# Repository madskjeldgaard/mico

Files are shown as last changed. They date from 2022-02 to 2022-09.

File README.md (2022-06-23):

# Mico - A tiny, cheap Raspberry Pi Pico midi controller

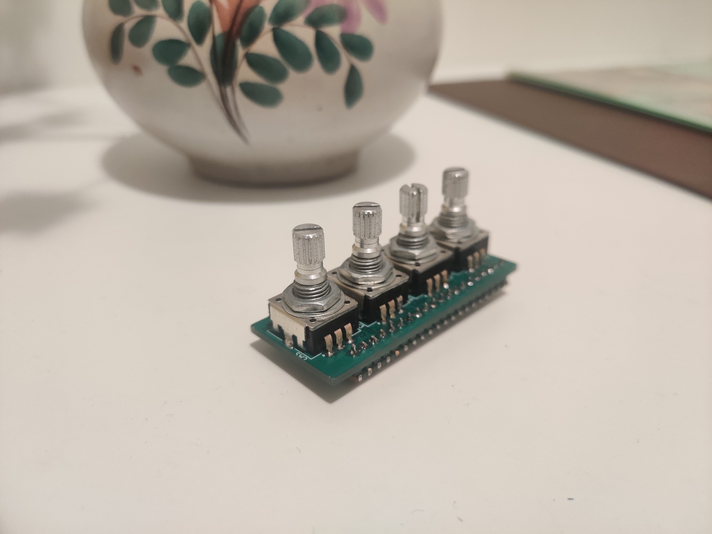
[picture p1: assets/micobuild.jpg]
mic build

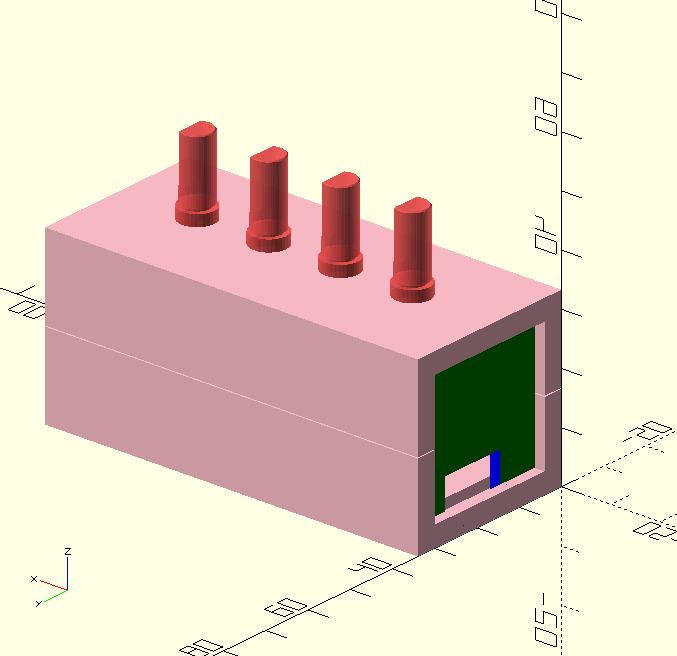
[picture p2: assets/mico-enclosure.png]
Enclosure
 

Mico is a small, cheap (~10 euros total) and super precise 14 bit midi controller based on the [Raspberry Pi Pico board](https://www.raspberrypi.com/products/raspberry-pi-pico/).

## Features
- 4 x detentless (smooth) encoders 
- Velocity: Slow movements result in microscopic changes (1/16000 of the max range approximately), fast movements in large changes.
- A variety of "clip modes" (cycle through them by pressing the button):
 	- wrap (when the value goes above max, it wraps back to 0) 
 	- clamp (clip at min and max value)
- 14 bit midi (as well as regular 7 bit midi)
- Cheap as chips and open sourced

## DEMO

There's a [demo here](https://vimeo.com/723291413).

## BOM

| Quantity | Part | Mouser Number |
|---|---|---|
| 1 | Raspberry Pi Pico rpi2040 | [474-DEV-17829](https://no.mouser.com/ProductDetail/SparkFun/DEV-17829?qs=sGAEpiMZZMv0NwlthflBi8NxDpSYKEiM3fbb2%2FVBX4k%3D) |
| 8 | 0.01uF capacitor, 0603 | [80-C0603C103M5R7411](https://no.mouser.com/ProductDetail/KEMET/C0603C103M5RAC7411?qs=ACslrEyEXNOtANB4TBkCnQ%3D%3D) |
| 16 | 10k resistors, 1%, 0603 | [603-RC0603FR-0710KL](https://no.mouser.com/ProductDetail/YAGEO/RC0603FR-0710KL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) |
| 4 | 15mm Detentless encoders | [652-PEC11R-4015K-N24](https://no.mouser.com/ProductDetail/652-PEC11R-4015K-N24)(knurled) / [PEC11R-4015F-N0024](https://no.mouser.com/ProductDetail/Bourns/PEC11R-4015F-N0024)(flat) |
| 2 | Female header (to sandwich between the boards)| n/a |
| 2 | Male header (to sandwich between the boards) | n/a |

## Uploading the firmware

Download the latest firmware from the release and locate the `mico.uf2` file. While plugging your Pico into your computer, press and hold the "BOOTSEL" button. It will show up as a storage device on your computer. Copy `mico.uf2` to this device. Done.

## Building and uploading the firmware (optional)

If you want to build the code and mess around with it, it is recommended to use a second Pico flashed with the [picoprobe](https://github.com/raspberrypi/picoprobe) firmware.

### Using picoprobe

```bash
cd software
mkdir build
cd build 
cmake ..
make && openocd -f interface/picoprobe.cfg -f target/rp2040.cfg -c "program mico.elf verify reset exit"
```
Debug:
```bash
openocd -f interface/picoprobe.cfg -f target/rp2040.cfg -s tcl
```

## Usage

### SuperCollider

There is an easy to use interface for this controller [here](https://github.com/madskjeldgaard/mico-sc).

## License

This work is shared under the *Attribution-NonCommercial-ShareAlike 4.0 International* license.

If you have questions about that, send me an email **mail at madskjeldgaard.dk**

## Credits

These projects were a big help and inspiration in making this:
- [schatzmann blog](https://www.pschatzmann.ch/home/2021/02/15/usb-midi-on-the-arduino-pico/) and [also this post](https://www.pschatzmann.ch/home/2021/02/19/tinyusb-a-simple-tutorial/)
- [pico-example-midi](https://github.com/infovore/pico-example-midi)
- [encoder-pio](https://github.com/pimoroni/pimoroni-pico) is from the pimoroni-pico library. MIT Licensed.

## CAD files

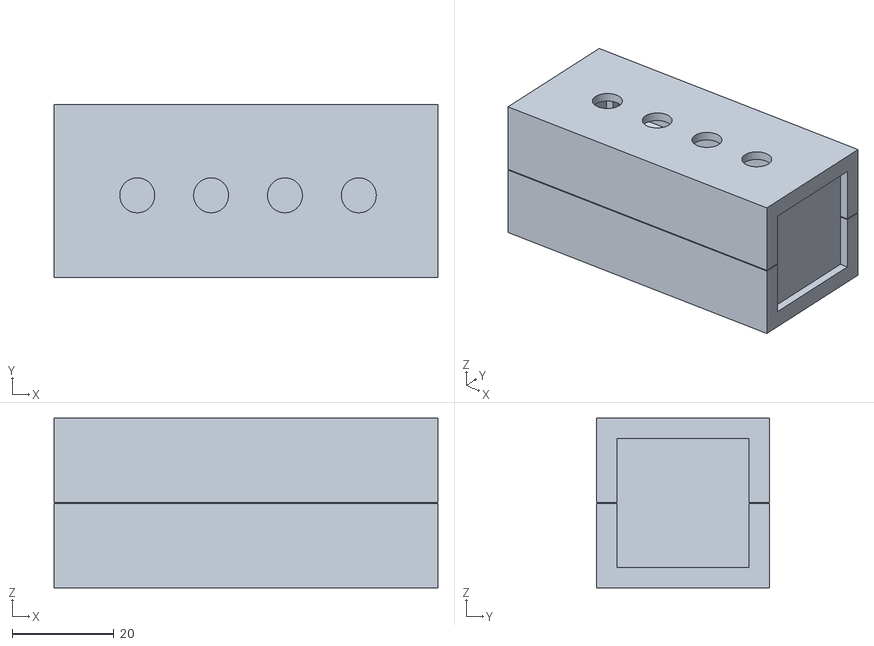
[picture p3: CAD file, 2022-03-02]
enclosure/mico_box.stl
75.4 x 34.0 x 33.3

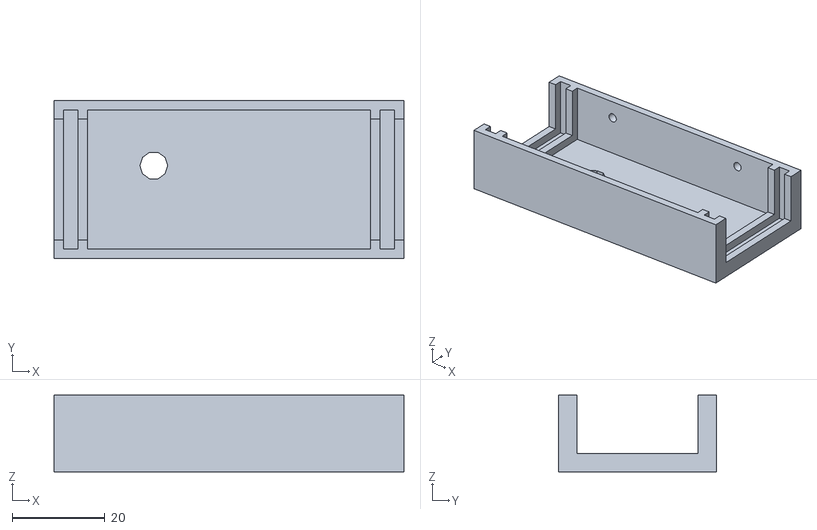
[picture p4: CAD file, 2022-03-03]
enclosure/print/bottom.stl
75.4 x 34.0 x 16.5

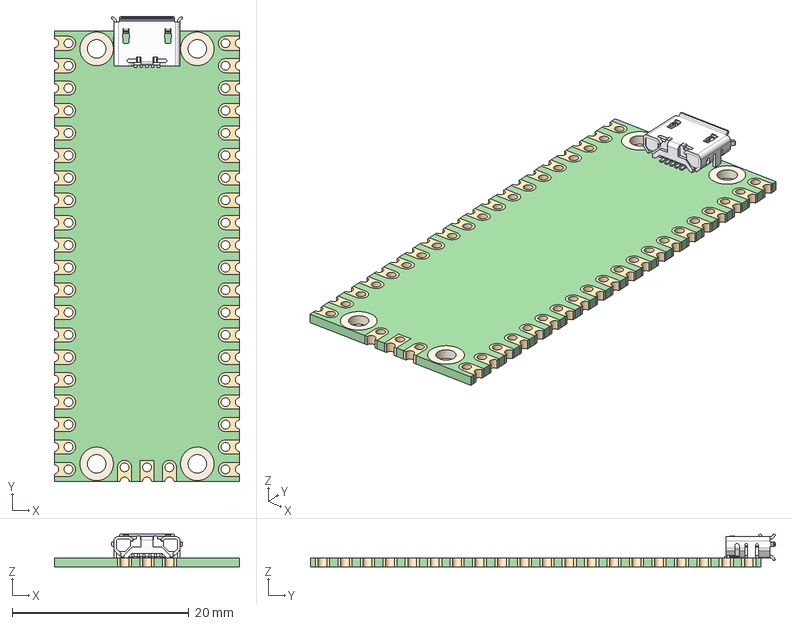
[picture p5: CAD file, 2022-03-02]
hardware/Raspberry Pi Pico.step
21.0 x 52.7 x 3.73 mm
PCB
Micro-USB_breakout v2

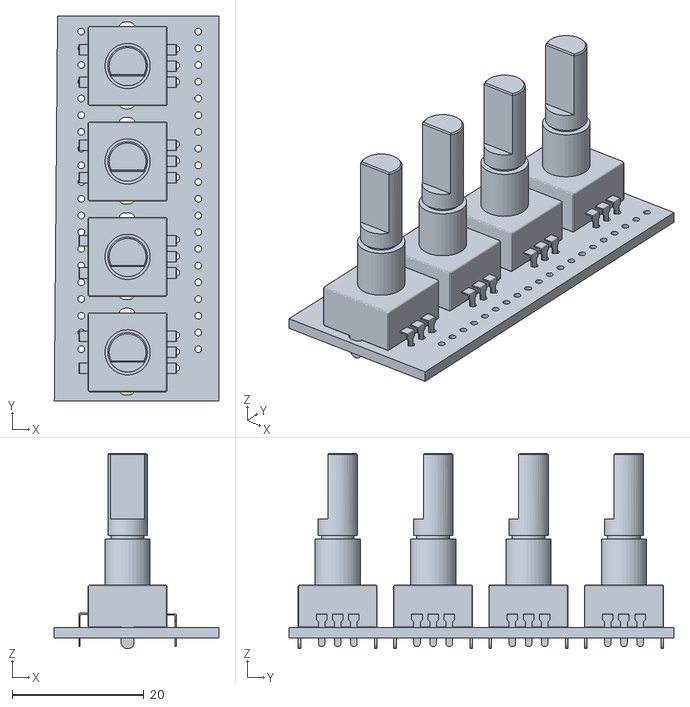
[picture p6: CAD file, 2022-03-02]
enclosure/mico-top-electronics.stl
25.0 x 58.5 x 29.7

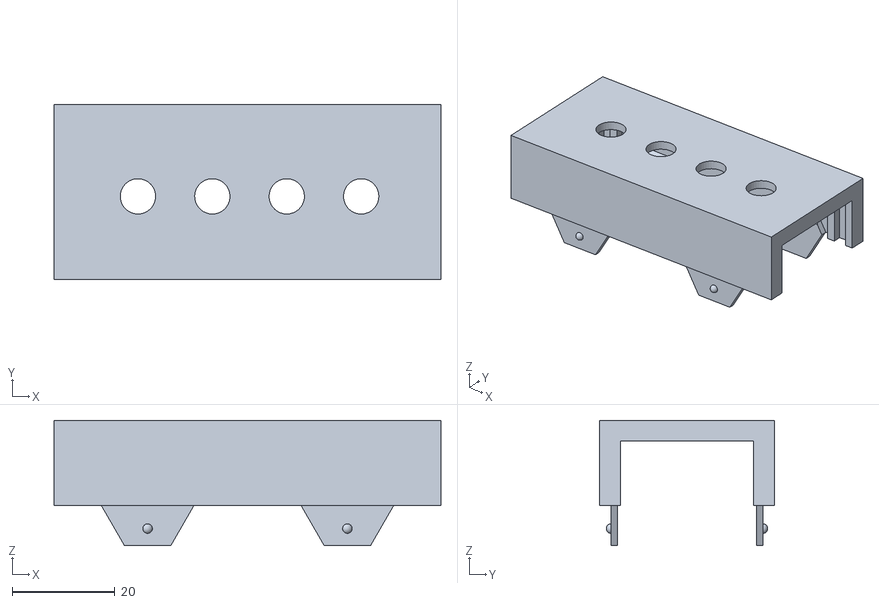
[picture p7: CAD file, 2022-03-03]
enclosure/print/top.stl
75.4 x 34.0 x 24.4

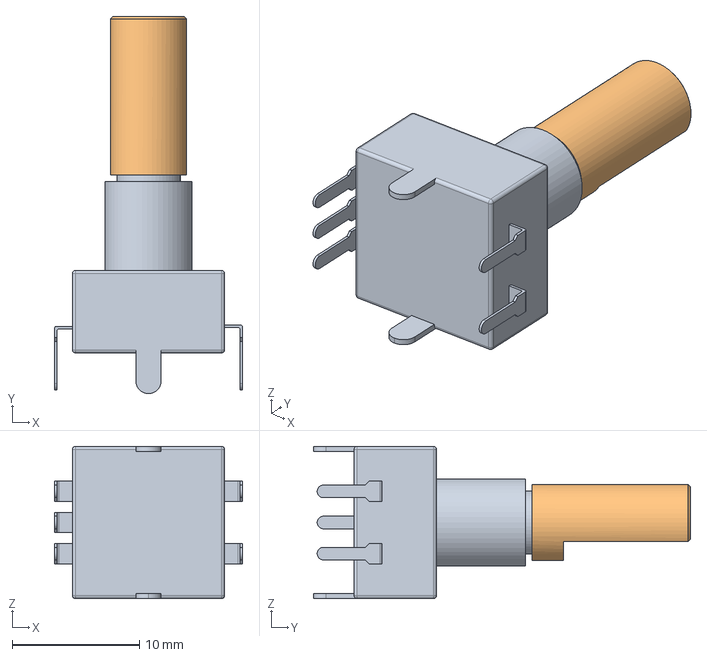
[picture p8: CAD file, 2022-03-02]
hardware/Rotary Encoder.step
14.8 x 29.7 x 12.0 mm

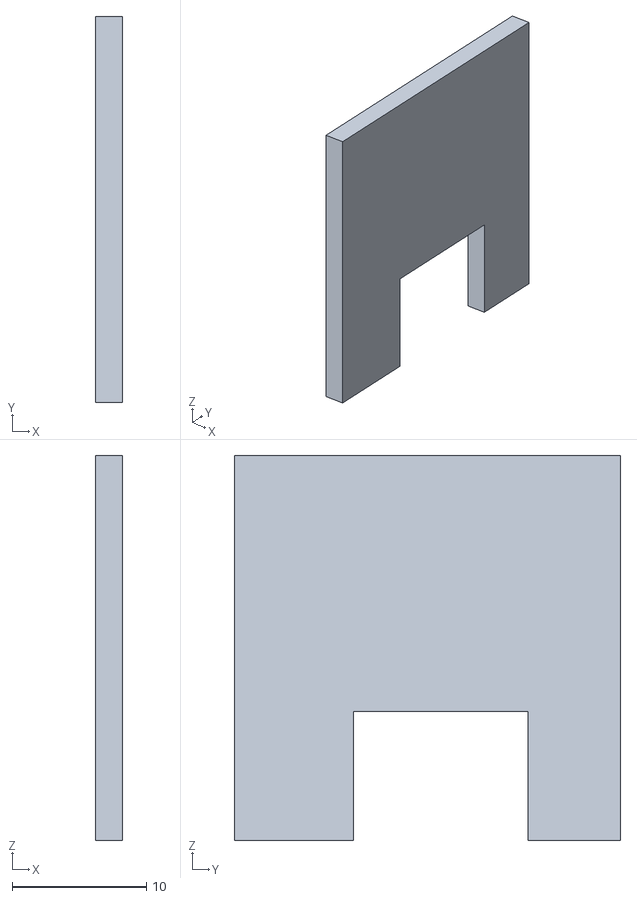
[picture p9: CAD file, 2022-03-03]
enclosure/print/back.stl
2.00 x 28.8 x 28.7

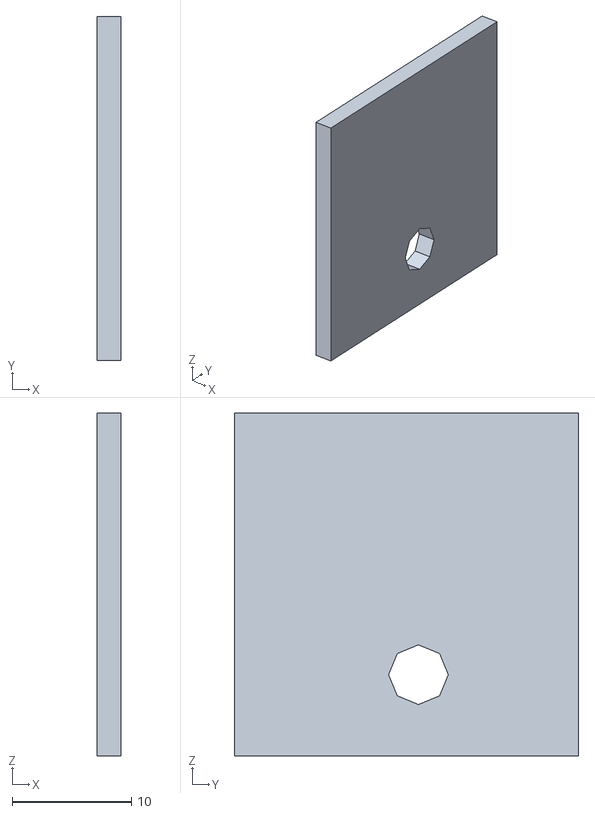
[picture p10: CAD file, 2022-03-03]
enclosure/print/front.stl
2.00 x 28.8 x 28.7

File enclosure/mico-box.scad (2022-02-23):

/* Box design originally by:
////////////////////////////////////////////////////////////////////
              -    FB Aka Heartman/Hearty 2016     -
              -   http://heartygfx.blogspot.com    -
              -       OpenScad Parametric Box      -
              -         CC BY-NC 3.0 License       -
////////////////////////////////////////////////////////////////////

Improved by jbebel:
http://github.com/jbebel/Ultimate-Box-Maker

To create a box, start by modifying the numerical parameters in the sections
below. This can be accomplished using a release of OpenSCAD newer than 2015.03.
As of the time of writing, this means that a development snapshot is required.
The Thingiverse Customizer may also potentially work, but at the time of
writing, it was inoperable.

The simplest choice is to hand-edit the .scad file. Feature toggles are
annotated with a comment. The other numerical parameters are measurements in
mm. Everything is parametrized, so if you double all the non-feature parameters
you will double the box size in every dimension. Certain parameters are derived
from other parameters. If you wish to override them, you may, but sensible
defaults have been chosen. Notably the design in this revision is particularly
PCB-centric, in that you should start with your PCB size and adjust the margins
around it to determine the box size. If you care more about the box size, you
can set the Length, Width, and Height explicitly, but read the comments around
them.

Once your box is sized appropriately, you can use the Panel modules to design
the holes and text for the front and back panels. Helper variables are provided
to assist you in positioning these holes relative to the PCB, if your holes are
for PCB-mounted components.

When you are ready to print, adjust the values in the "STL element to export"
section, and export each part one at a time.

Experimental options are provided for a screwless design, but these are
untested. In particular, the box fixation tabs may need thicknesses adjusted
in order to have the appropriate flexibility.
*/

// preview[view:north east, tilt:top diagonal]
//----------------------- Box parameters ---------------------------

/* [Box options] */
// - Wall thickness
Thick = 3;
// - Panel thickness
PanelThick = 3;
// - Font Thickness
FontThick = 0.5;
// - Filet Radius
Filet = 0;
// - 0 for beveled, 1 for rounded
Round = 0; // [0:No, 1:Yes]
// - Printer margin around interior cutouts
CutoutMargin = 0.3;
// - Margin between mating parts
PartMargin = 0.1;
// - PCB feet? (x4)
PCBFeet = 1; // [0:No, 1:Yes]
// - Decorations?
Decorations = 0; // [0:No, 1:Yes]
// - Decorations to ventilation holes
Vent = 0; // [0:No, 1:Yes]
// - Decoration-Holes width (in mm)
Vent_width = 1.5;
// - Tolerance (Panel/rails gap on one edge)
PanelThickGap = CutoutMargin + PartMargin;
PanelVerticalGap = PartMargin;
PanelHorizontalGap = CutoutMargin + PartMargin;

/* [Box Fixation Tabs] */
// - Side screw hole (or snap) diameter
ScrewHole = 2.2606;
// - Screw thread major diameter for outer shell
BoxHole = 2.8448;
// Thickness of fixation tabs
TabThick = 2;
// Back left tab
BLTab = 1; // [0:Bottom, 1:Top]
// Back right tab
BRTab = 1; // [0:Bottom, 1:Top]
// Front left tab
FLTab = 1; // [0:Bottom, 1:Top]
// Front right tab
FRTab = 1; // [0:Bottom, 1:Top]
// EXPERIMENTAL: Snap tabs
SnapTabs = 1; // [0:Screws, 1:Snaps]

/* [PCB options] */
// - PCB Length
PCBLength = 58.5;
// - PCB Width
PCBWidth = 25;
// - PCB Thickness
PCBThick = 1.6;
// You likely need to maintain |TabThick| margin on the left and right for tabs
// and whatnot.
// - Margin between front panel and PCB
FrontEdgeMargin = 1;
// - Margin between back panel and PCB
BackEdgeMargin = 1;
// - Margin between left wall and PCB
LeftEdgeMargin = 1;
// - Margin between right wall and PCB
RightEdgeMargin = 1;
// - Margin between top of PCB and box top.
TopMargin = 30; // @TODO

/* [PCB_Feet] */
// - Foot height above box interior
FootHeight = 8;
// - Foot diameter
FootDia = 8;
// - Hole diameter, or peg for screwless design
FootHole = 2.2606; // tap size for #4 coarse-thread
// - EXPERIMENTAL Screwless design
Screwless = 0; // [0:Screws, 1:Screwless]
FootFilet = FootHeight/4;

// Foot centers are specified as distance from PCB back-left corner.
// X is along the "length" axis, and Y is along the "width" axis.
// - Foot 1 distance from back PCB edge
Foot1X = 5;
// - Foot 1 distance from left PCB edge
Foot1Y = 5;
// - Foot 2 distance from back PCB edge
Foot2X = 5;
// - Foot 2 distance from right PCB edge
Foot2YFromEdge = 5;
Foot2Y = PCBWidth - Foot2YFromEdge;
// - Foot 3 distance from front PCB edge
Foot3XFromEdge = 5;
Foot3X = PCBLength - Foot3XFromEdge;
// - Foot 3 distance from left PCB edge
Foot3Y = 5;
// - Foot 4 distance from front PCB edge
Foot4XFromEdge = 5;
Foot4X = PCBLength - Foot4XFromEdge;
// - Foot 4 distance from right PCB edge
Foot4YFromEdge = 5;
Foot4Y = PCBWidth - Foot4YFromEdge;

/* [STL element to export] */
// - Top shell
TShell = 0; // [0:No, 1:Yes]
// - Bottom shell
BShell = 1; // [0:No, 1:Yes]
// - Front panel
FPanL = 1; // [0:No, 1:Yes]
// - Back panel
BPanL = 1; // [0:No, 1:Yes]
// - Panel holes and text
PanelFeatures = 1; // [0:No, 1:Yes]

/* [Hidden] */
// - Shell color
Couleur1 = "Orange";
// - Panel color
Couleur2 = "OrangeRed";
// - Text color
TextColor = "White";
// - making decorations thicker if it is a vent to make sure they go through
// shell
// Add a small number to Thick in case Filet is 0.
Dec_Thick = Vent ? Thick*1.001 + Filet : Thick/2;
// Separate vents with a square pillar by default.
Dec_Spacing = Thick + Vent_width;
// X offset to center of first vent
Dec_Offset = Thick*2 + PanelThick + PanelThickGap*2 + Dec_Spacing - Vent_width/2;

// Resolution based on Round parameter. Set this first number to something
// smaller to speed up processing. It should always be a multiple of 4.
Resolution = Round ? 100: 4;

/* Calculate box dimensions from PCB. If you want a more box-centric design
   where the outer diameter of the box matters more than the margins around
   the PCB you can set these manually. The PCB will still be placedaccording
   to the left and back margins, and if you want to use the screwless box
   design, you will need to set the TopMargin to
   (Height - Thick*2 - FootHeight - PCBThick)
*/
Length = PCBLength + FrontEdgeMargin + BackEdgeMargin + ((Thick + PanelThick + PanelThickGap*2)*2);
Width = PCBWidth + LeftEdgeMargin + RightEdgeMargin + Thick*2;
Height = FootHeight + PCBThick + TopMargin + Thick*2;
echo("Box: ", Length=Length, Width=Width, Height=Height);
// X position inset of mounting holes and tabs
MountInset = Thick*3 + PanelThick + PanelThickGap*2 + ScrewHole*4;

// Calculate panel dimensions from box dimensions.
PanelWidth = Width - Thick*2 - PanelHorizontalGap*2;
PanelHeight = Height - Thick*2 - PanelVerticalGap*2;

/*  Panel Manager

    Use the below 4 modules to produce holes and text on the front and back
    panels. The holes modules should contain instances of SquareHole or
    CylinderHole defined later in this file. The text modules should contain
    instances of LText or CText defined later in this file. It is
    recommended to use variables that you define for your needs to create
    the size and positions of these objects.
*/

// Calculate board-relative positions with respect to the panel, for
// convenience in placing panel elements.
TopOfBoardWRTPanel = FootHeight + PCBThick - PanelVerticalGap;
LeftEdgeOfBoardWRTFPanel = LeftEdgeMargin - PanelHorizontalGap;
LeftEdgeOfBoardWRTBPanel = RightEdgeMargin - PanelHorizontalGap;
// Visible panel edges
PanelBottomEdge = Thick - PanelVerticalGap;
PanelTopEdge = PanelHeight - Thick + PanelVerticalGap;
PanelLeftEdge = Thick - PanelHorizontalGap;
PanelRightEdge = PanelWidth - Thick + PanelHorizontalGap;

// Holes for front panel
module FPanelHoles() {
    // SquareHole(On/Off, Xpos,Ypos,Length,Width,Filet)
    /* SquareHole(1, 20, 20, 15, 10, 1); */
    /* SquareHole(1, 40, 20, 15, 10, 1); */
    /* SquareHole(1, 60, 20, 15, 10, 1); */
    // CylinderHole(On/Off, Xpos, Ypos, Diameter)
    /* CylinderHole(1, 27, 40, 8); */
    /* CylinderHole(1, 47, 40, 8); */
    /* CylinderHole(1, 67, 40, 8); */
    /* SquareHole(1, 20, 50, 80, 30, 3); */
    /* CylinderHole(1, 93, 30, 10); */
    /* SquareHole(1, 120, 20, 30, 60, 3); */
}

// Text for front panel
module FPanelText() {
    // LText(On/Off, Xpos, Ypos, "Font", Size, "Text", "HAlign", "VAlign")
    /* LText(1, 20, 83, "Arial Black", 4, "Digital Screen", HAlign="left"); */
    /* LText(1, 120, 83, "Arial Black", 4, "Level", HAlign="left"); */
    /* LText(1, 20, 11, "Arial Black", 6, "  1     2      3", HAlign="left"); */
    // CText(On/Off, Xpos, Ypos, "Font", Size, Diameter, Arc(Deg), Starting Angle(Deg),"Text")
    /* CText(1, 93, 29, "Arial Black", 4, 10, 180, 0, */
    /*       ["1", "." , "3", "." , "5", "." , "7", "." , "9", "." , "11"]); */
}
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

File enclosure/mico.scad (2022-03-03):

/* Box design originally by:
////////////////////////////////////////////////////////////////////
              -    FB Aka Heartman/Hearty 2016     -
              -   http://heartygfx.blogspot.com    -
              -       OpenScad Parametric Box      -
              -         CC BY-NC 3.0 License       -
////////////////////////////////////////////////////////////////////

Improved by jbebel:
http://github.com/jbebel/Ultimate-Box-Maker

To create a box, start by modifying the numerical parameters in the sections
below. This can be accomplished using a release of OpenSCAD newer than 2015.03.
As of the time of writing, this means that a development snapshot is required.
The Thingiverse Customizer may also potentially work, but at the time of
writing, it was inoperable.

The simplest choice is to hand-edit the .scad file. Feature toggles are
annotated with a comment. The other numerical parameters are measurements in
mm. Everything is parametrized, so if you double all the non-feature parameters
you will double the box size in every dimension. Certain parameters are derived
from other parameters. If you wish to override them, you may, but sensible
defaults have been chosen. Notably the design in this revision is particularly
PCB-centric, in that you should start with your PCB size and adjust the margins
around it to determine the box size. If you care more about the box size, you
can set the Length, Width, and Height explicitly, but read the comments around
them.

Once your box is sized appropriately, you can use the Panel modules to design
the holes and text for the front and back panels. Helper variables are provided
to assist you in positioning these holes relative to the PCB, if your holes are
for PCB-mounted components.

When you are ready to print, adjust the values in the "STL element to export"
section, and export each part one at a time.

Experimental options are provided for a screwless design, but these are
untested. In particular, the box fixation tabs may need thicknesses adjusted
in order to have the appropriate flexibility.
*/

// preview[view:north east, tilt:top diagonal]
//----------------------- Box parameters ---------------------------

USBCutX=5;
USBCutY=18;
USBCutZ=8;
USBW=13;
USBH=10;
USBD=10;

// TODO: This is kind of guesswork
BUTTONX=21.5;
BUTTONY=23;
BUTTONZ=-3;

BUTTONW=5;
BUTTONH=25;
BUTTOND=6;

/* [Box options] */
// - Wall thickness
Thick = 1.0;
// - Panel thickness
PanelThick = 1.0;
// - Font Thickness
FontThick = 0.5;
// - Filet Radius
Filet = 2;
// - 0 for beveled, 1 for rounded
Round = 0; // [0:No, 1:Yes]
// - Printer margin around interior cutouts
CutoutMargin = 0.2;
// - Margin between mating parts
PartMargin = 0.05;
// - PCB feet? (x4)
PCBFeet = 0; // [0:No, 1:Yes]
// - Decorations?
Decorations = 0; // [0:No, 1:Yes]
// - Decorations to ventilation holes
Vent = 0; // [0:No, 1:Yes]
// - Decoration-Holes width (in mm)
Vent_width = 0.5;
// - Tolerance (Panel/rails gap on one edge)
PanelThickGap = CutoutMargin + PartMargin;
PanelVerticalGap = PartMargin;
PanelHorizontalGap = CutoutMargin + PartMargin;

/* [Box Fixation Tabs] */
// - Side screw hole (or snap) diameter
ScrewHole = 2.2606;
// - Screw thread major diameter for outer shell
BoxHole = 2.8448;
// Thickness of fixation tabs
TabThick = 1.5;
// Back left tab
BLTab = 1; // [0:Bottom, 1:Top]
// Back right tab
BRTab = 1; // [0:Bottom, 1:Top]
// Front left tab
FLTab = 1; // [0:Bottom, 1:Top]
// Front right tab
FRTab = 1; // [0:Bottom, 1:Top]
// EXPERIMENTAL: Snap tabs
SnapTabs = 1; // [0:Screws, 1:Snaps]

/* [PCB options] */
// - PCB Length
PCBLength = 60.0;
// - PCB Width
PCBWidth = 26;
// - PCB Thickness
PCBThick = 1.6;
// You likely need to maintain |TabThick| margin on the left and right for tabs
// and whatnot.
// - Margin between front panel and PCB
FrontEdgeMargin = 3;
// - Margin between back panel and PCB
BackEdgeMargin = 2;
// - Margin between left wall and PCB
LeftEdgeMargin = 2;
// - Margin between right wall and PCB
RightEdgeMargin = 2;
// - Margin between top of PCB and box top.
TopMargin = 27.5; // @TODO

/* [PCB_Feet] */
// - Foot height above box interior
FootHeight = 0;
// - Foot diameter
FootDia = 8;
// - Hole diameter, or peg for screwless design
FootHole = 2.2606; // tap size for #4 coarse-thread
// - EXPERIMENTAL Screwless design
Screwless = 0; // [0:Screws, 1:Screwless]
FootFilet = FootHeight/4;

// Foot centers are specified as distance from PCB back-left corner.
// X is along the "length" axis, and Y is along the "width" axis.
// - Foot 1 distance from back PCB edge
Foot1X = 5;
// - Foot 1 distance from left PCB edge
Foot1Y = 5;
// - Foot 2 distance from back PCB edge
Foot2X = 5;
// - Foot 2 distance from right PCB edge
Foot2YFromEdge = 5;
Foot2Y = PCBWidth - Foot2YFromEdge;
// - Foot 3 distance from front PCB edge
Foot3XFromEdge = 5;
Foot3X = PCBLength - Foot3XFromEdge;
// - Foot 3 distance from left PCB edge
Foot3Y = 5;
// - Foot 4 distance from front PCB edge
Foot4XFromEdge = 5;
Foot4X = PCBLength - Foot4XFromEdge;
// - Foot 4 distance from right PCB edge
Foot4YFromEdge = 5;
Foot4Y = PCBWidth - Foot4YFromEdge;

TShell = 1;
BShell = 1;
FPanL = 1;
BPanL = 1;
/* [STL element to export] */
// - Top shell
Solo = 0; // 0 = not solo, 1 = top, 2 = bottom, 3 = front, 4 = back

PanelFeatures = 0; // [0:No, 1:Yes]

/* [Hidden] */
// - Shell color
Couleur1 = "Pink";
// - Panel color
Couleur2 = "Green";
// - Text color
TextColor = "White";
// - making decorations thicker if it is a vent to make sure they go through
// shell
// Add a small number to Thick in case Filet is 0.
Dec_Thick = Vent ? Thick*1.001 + Filet : Thick/2;
// Separate vents with a square pillar by default.
Dec_Spacing = Thick + Vent_width;
// X offset to center of first vent
Dec_Offset = Thick*2 + PanelThick + PanelThickGap*2 + Dec_Spacing - Vent_width/2;

// Resolution based on Round parameter. Set this first number to something
// smaller to speed up processing. It should always be a multiple of 4.
Resolution = Round ? 100: 4;

/* Calculate box dimensions from PCB. If you want a more box-centric design
   where the outer diameter of the box matters more than the margins around
   the PCB you can set these manually. The PCB will still be placedaccording
   to the left and back margins, and if you want to use the screwless box
   design, you will need to set the TopMargin to
   (Height - Thick*2 - FootHeight - PCBThick)
*/
Length = PCBLength + FrontEdgeMargin + BackEdgeMargin + ((Thick + PanelThick + PanelThickGap*2)*2);
Width = PCBWidth + LeftEdgeMargin + RightEdgeMargin + Thick*2;
Height = FootHeight + PCBThick + TopMargin + Thick*2;
echo("Box: ", Length=Length, Width=Width, Height=Height);
// X position inset of mounting holes and tabs
MountInset = Thick*3 + PanelThick + PanelThickGap*2 + ScrewHole*4;

// Calculate panel dimensions from box dimensions.
PanelWidth = Width - Thick*2 - PanelHorizontalGap*2;
PanelHeight = Height - Thick*2 - PanelVerticalGap*2;

/*  Panel Manager

    Use the below 4 modules to produce holes and text on the front and back
    panels. The holes modules should contain instances of SquareHole or
    CylinderHole defined later in this file. The text modules should contain
    instances of LText or CText defined later in this file. It is
    recommended to use variables that you define for your needs to create
    the size and positions of these objects.
*/

// Calculate board-relative positions with respect to the panel, for
// convenience in placing panel elements.
TopOfBoardWRTPanel = FootHeight + PCBThick - PanelVerticalGap;
LeftEdgeOfBoardWRTFPanel = LeftEdgeMargin - PanelHorizontalGap;
LeftEdgeOfBoardWRTBPanel = RightEdgeMargin - PanelHorizontalGap;
// Visible panel edges
PanelBottomEdge = Thick - PanelVerticalGap;
PanelTopEdge = PanelHeight - Thick + PanelVerticalGap;
PanelLeftEdge = Thick - PanelHorizontalGap;
PanelRightEdge = PanelWidth - Thick + PanelHorizontalGap;

// Holes for front panel
module FPanelHoles() {
    // SquareHole(On/Off, Xpos,Ypos,Length,Width,Filet)
    /* SquareHole(1, 20, 20, 15, 10, 1); */
    /* SquareHole(1, 40, 20, 15, 10, 1); */
    /* SquareHole(1, 60, 20, 15, 10, 1); */
    // CylinderHole(On/Off, Xpos, Ypos, Diameter)
    /* CylinderHole(1, 27, 40, 8); */
    /* CylinderHole(1, 47, 40, 8); */
    /* CylinderHole(1, 67, 40, 8); */
    /* SquareHole(1, 20, 50, 80, 30, 3); */
    /* CylinderHole(1, 93, 30, 10); */
    /* SquareHole(1, 120, 20, 30, 60, 3); */
}

// If using both the top and pico, the scad compiler will complain of meshes not being closed. Settings this to true will show the full electronics but it should be false when compiling the final model.
FullElectronics=false;
module Electronics(){
	// Electronics
	translate([-57.75,-120,22.8])rotate([0,0,90])
		if(FullElectronics){
			import("mico-all-electronics.stl", center=true);
		} else {
			import("mico-top-electronics.stl", center=true);
		}
}
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

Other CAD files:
hardware/KiCad-RP-Pico/SketchUp Model/Pico.skp

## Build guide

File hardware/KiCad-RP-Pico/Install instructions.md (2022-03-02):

# Install instructions

## 1. Copy the files locally

Copy the `RP-Pico Libraries` folder wherever you like on your computer.

## 2. Install the Raspberry Pi Pico board schema symbol

Use the `KiCad | Preferences | Manage Symbol Libraries...` command to manage the symbol library:

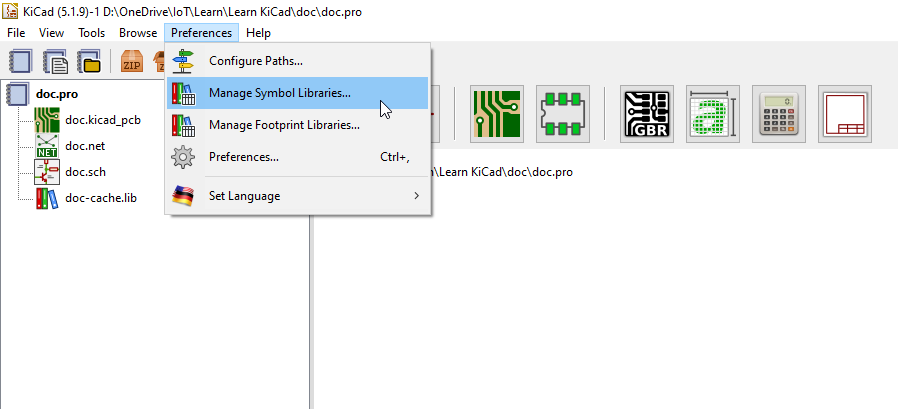
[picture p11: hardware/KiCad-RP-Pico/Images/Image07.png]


then select the global tab and click on the folder button:

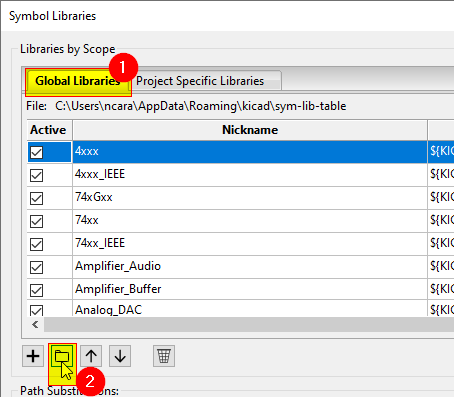
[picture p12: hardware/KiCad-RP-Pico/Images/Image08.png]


navigate to the `RP-Pico Libraries` folder, select the `MCU_RaspberryPi_and_Boards.lib` file and open it:

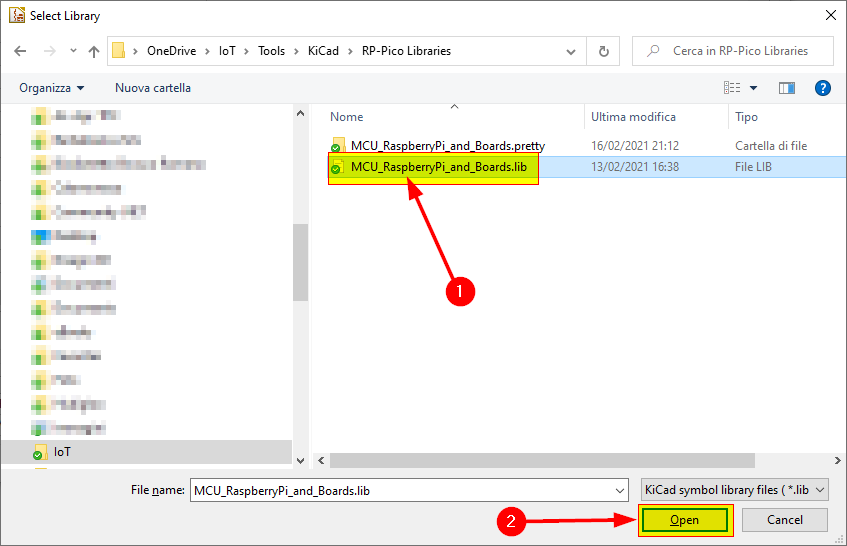
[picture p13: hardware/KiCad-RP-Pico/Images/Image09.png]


et voilà, the first step is completed:

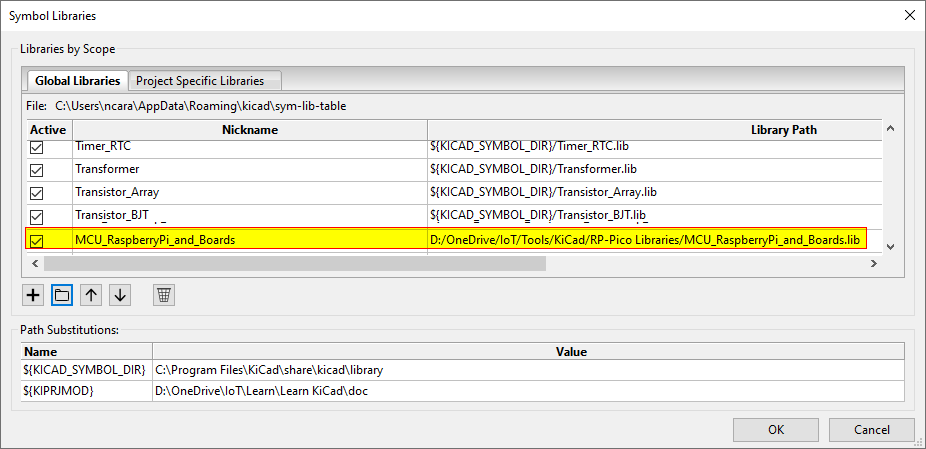
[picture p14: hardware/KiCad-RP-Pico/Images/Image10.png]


You can now close the symbol libraries manager window.

## 3. Install the Raspberry Pi Pico board footprint

You can use a similar approach to add the footprint to the footprint libraries manager, but I've found some issues that I've solved using the footprint editor, so here are the steps I suggest you to follow:

Open the footprint editor

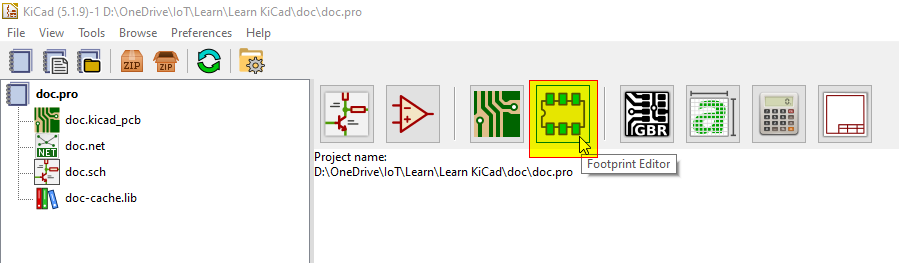
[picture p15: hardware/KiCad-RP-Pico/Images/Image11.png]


wait for the footprints to load... then use the `File | Add Library` command:

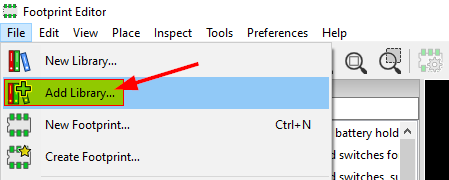
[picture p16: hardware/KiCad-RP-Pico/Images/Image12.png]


select the `MCU_RaspberriPi_and_Boards.pretty` folder (yes, the folder represent a footprint library on KiCad):

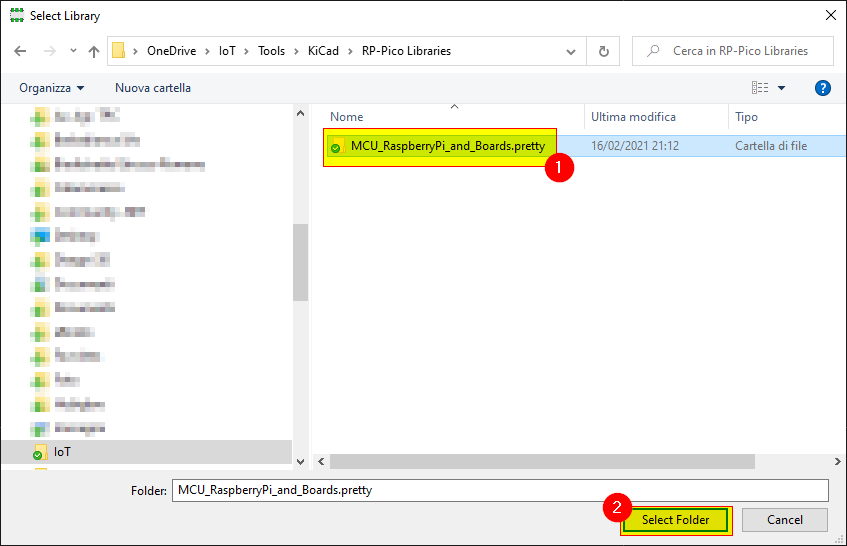
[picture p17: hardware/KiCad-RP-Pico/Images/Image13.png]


and confirm the `Global` choice:

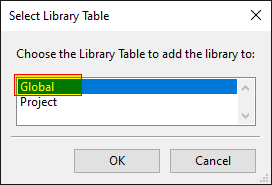
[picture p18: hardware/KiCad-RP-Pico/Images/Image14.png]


Now the library is installed on KiCad with the Raspberry Pi Pico footprint (double click on it to see it on the editor pane):

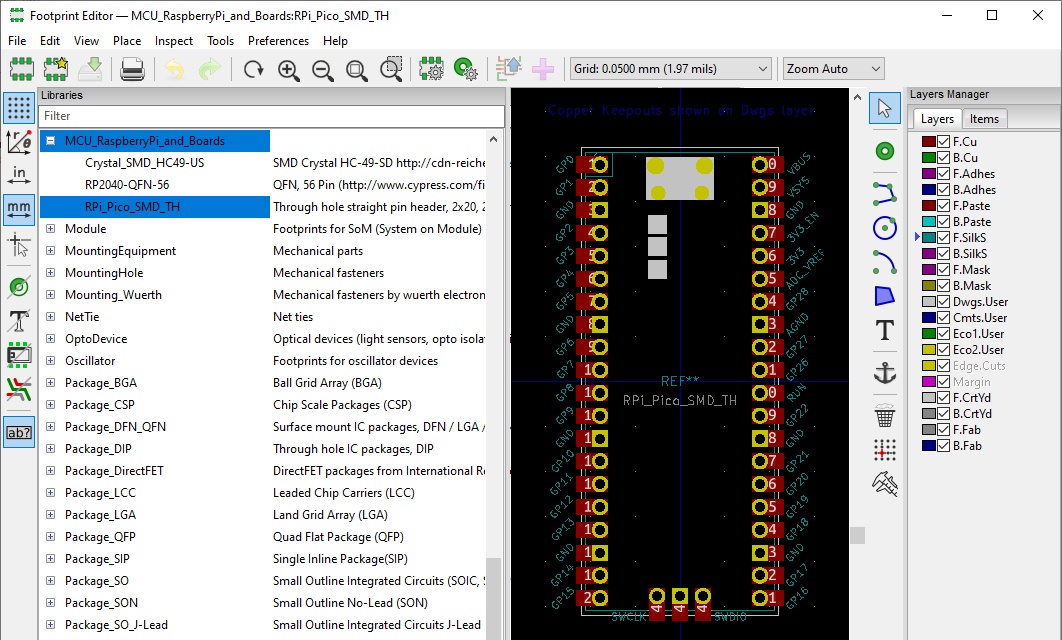
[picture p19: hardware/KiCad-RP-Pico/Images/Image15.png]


Don't close the windows as the next step start from here.

## 4. Install the Raspberry Pi Pico board footprint 3D visual

If not already open, open the the footprint editor

symbol library manager

double click on the `RPi_Pico_SMD_TH` footprint from the `MCU_RaspberriPi_and_Boards` library and then click on the `Footprint properties` icon:

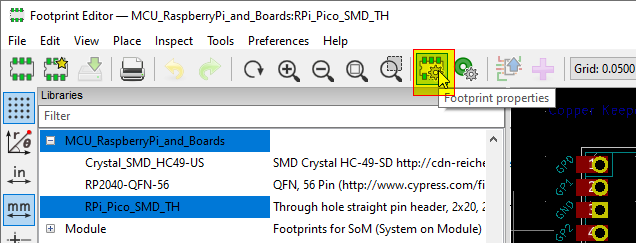
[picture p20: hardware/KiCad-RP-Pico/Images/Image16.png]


In the footprint properties window, first select the `3D Settings` tab. Please note that the preview shows only the PCB board with the footprint added on step 3, without any 3D representation of the Raspberry Pi Pico board. Now click on the folder icon to add the 3D model:

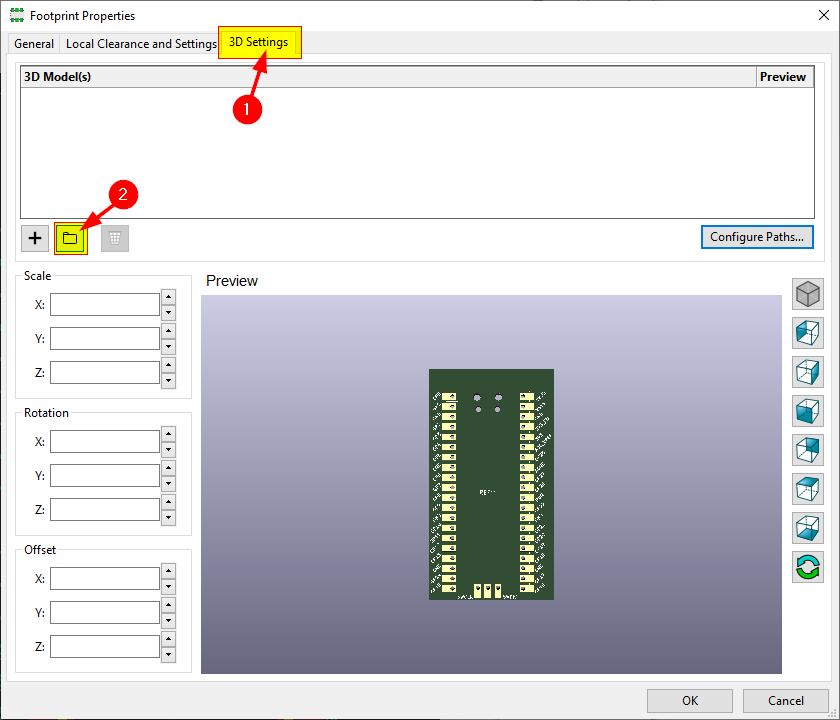
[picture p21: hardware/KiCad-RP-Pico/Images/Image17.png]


Navigate to the `RP-Pico Libraries` folder, select the `Pico.wrl` file and wait until the model is shown in the right panel, then confirm with OK:

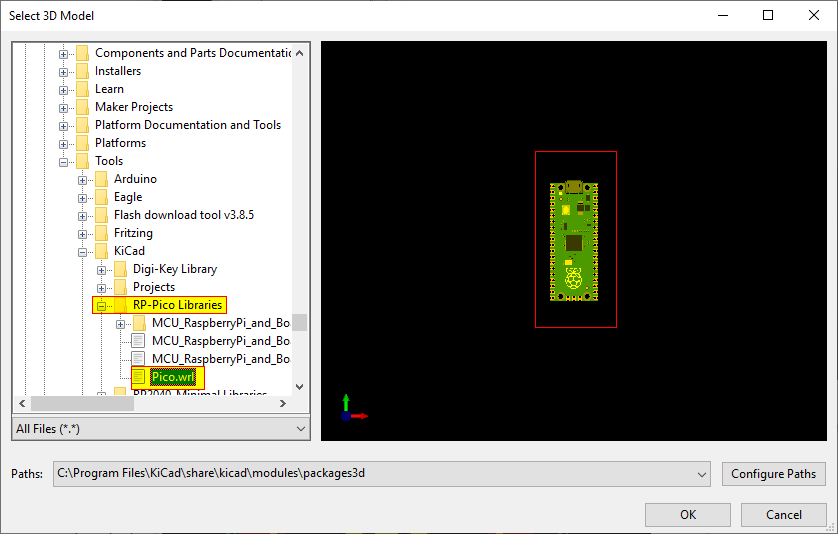
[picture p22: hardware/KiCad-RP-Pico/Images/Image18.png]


The model is already scaled and translated to match the footprint:

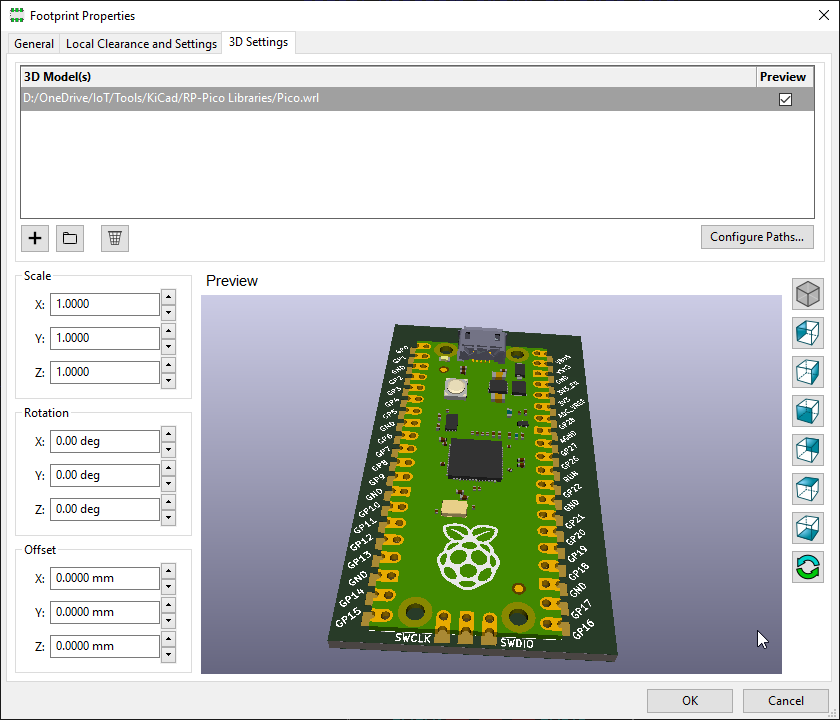
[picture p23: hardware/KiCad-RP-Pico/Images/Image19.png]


now close the `Footprint Properties` window, and the `Footprint Editor`, obviously saving the changes.

## Conclusion

Now that you've installed the schema and footprint and added the 3D model to the footprint, you can use the Raspberry Pi Pico board on your KiCad projects.

I've also added a test KiCad Project on the `Test` folder, that you can use to see an example of it.

Have fun!

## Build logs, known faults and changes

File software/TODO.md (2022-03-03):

Bugs:
- Button hole in enclosure
- debug hole in enclosure
- Properly clamp values under 0 in the encoder itself.

Features:
- VelocityTrigger
- Inverse on adjacent midi channel. So if enc1 is high on midi channel 0, then send inverse of that to 1 on channel 1
- Set wrap mode per encoder (hold button and wiggle encoder)
- Interpolation / lag
- Add interpolated random envelope mode
- save options in flash: https://github.com/raspberrypi/pico-examples/blob/master/flash/program/flash_program.c

Misc:
- Move encoder stuff to seperate library
- Remove all the microstep leftovers from gpio-encoder
- semaphores around usb midi stuff like in arduino_pico?

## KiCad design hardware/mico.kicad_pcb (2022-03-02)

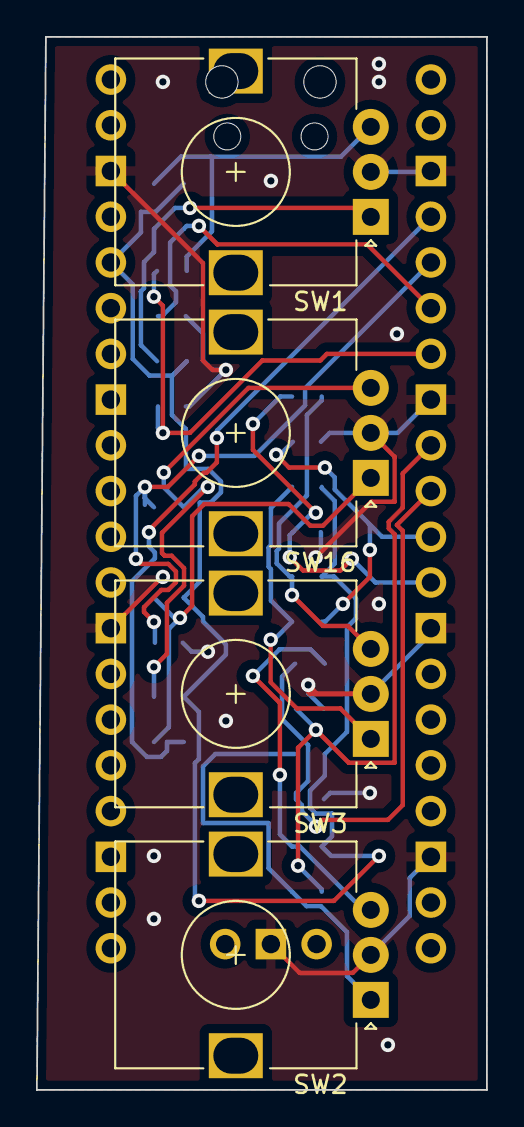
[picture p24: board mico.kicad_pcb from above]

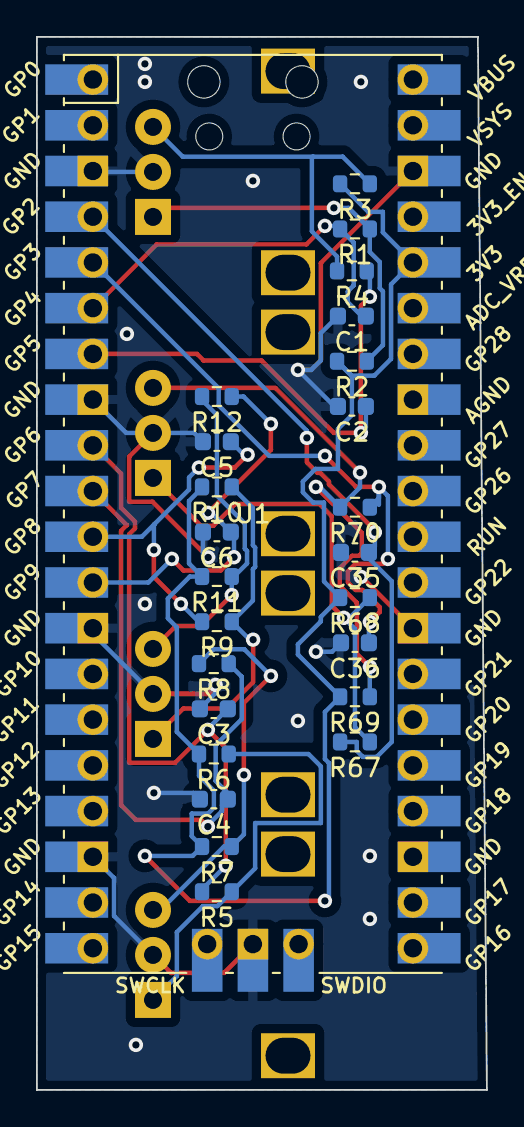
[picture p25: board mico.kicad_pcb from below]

Board: 2 copper layers, 25.0 x 58.5 mm, 29 parts (25 on the bottom side), 18 nets.

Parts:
C1, C2, C3, C4, C5, C6, C35, C36: 0.01uF; C_0603_1608Metric
R1, R2, R3, R4, R5, R6, R7, R8, R9, R10, R11, R12, R67, R68, R69, R70: 10k; R_0603_1608Metric
SW1, SW2, SW3, SW16: Rotary_Encoder; RotaryEncoder_Alps_EC12E_Vertical_H20mm
U1: Pico; RPi_Pico_SMD_TH

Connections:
+3V3: R2.2, R3.2, R6.2, R7.2, R10.2, R11.2, R68.2, R69.2, U1.36 (3V3)
/encoder_no_switch1/A: C1.1, R1.2, U1.6 (GPIO4)
/encoder_no_switch1/B: C2.1, R4.1, U1.7 (GPIO5)
/encoder_no_switch2/A: C3.1, R5.2, U1.9 (GPIO6)
/encoder_no_switch2/B: C4.1, R8.1, U1.10 (GPIO7)
/encoder_no_switch3/A: C5.1, R9.2, U1.11 (GPIO8)
/encoder_no_switch3/B: C6.1, R12.1, U1.12 (GPIO9)
/encoder_no_switch/A: C35.1, R67.2, U1.4 (GPIO2)
/encoder_no_switch/B: C36.1, R70.1, U1.5 (GPIO3)
GND: C1.2, C2.2, C3.2, C4.2, C5.2, C6.2, C35.2, C36.2, SW1.C, SW2.C, SW3.C, SW16.C, U1.3 (GND), U1.8 (GND), U1.13 (GND), U1.18 (GND), U1.28 (GND), U1.38 (GND), U1.42 (GND)
unnamed: R1.1, R2.1, SW1.A
unnamed: R3.1, R4.2, SW1.B
unnamed: R5.1, R6.1, SW2.A
unnamed: R7.1, R8.2, SW2.B
unnamed: R9.1, R10.1, SW3.A
unnamed: R11.1, R12.2, SW3.B
unnamed: R67.1, R68.1, SW16.A
unnamed: R69.1, R70.2, SW16.B

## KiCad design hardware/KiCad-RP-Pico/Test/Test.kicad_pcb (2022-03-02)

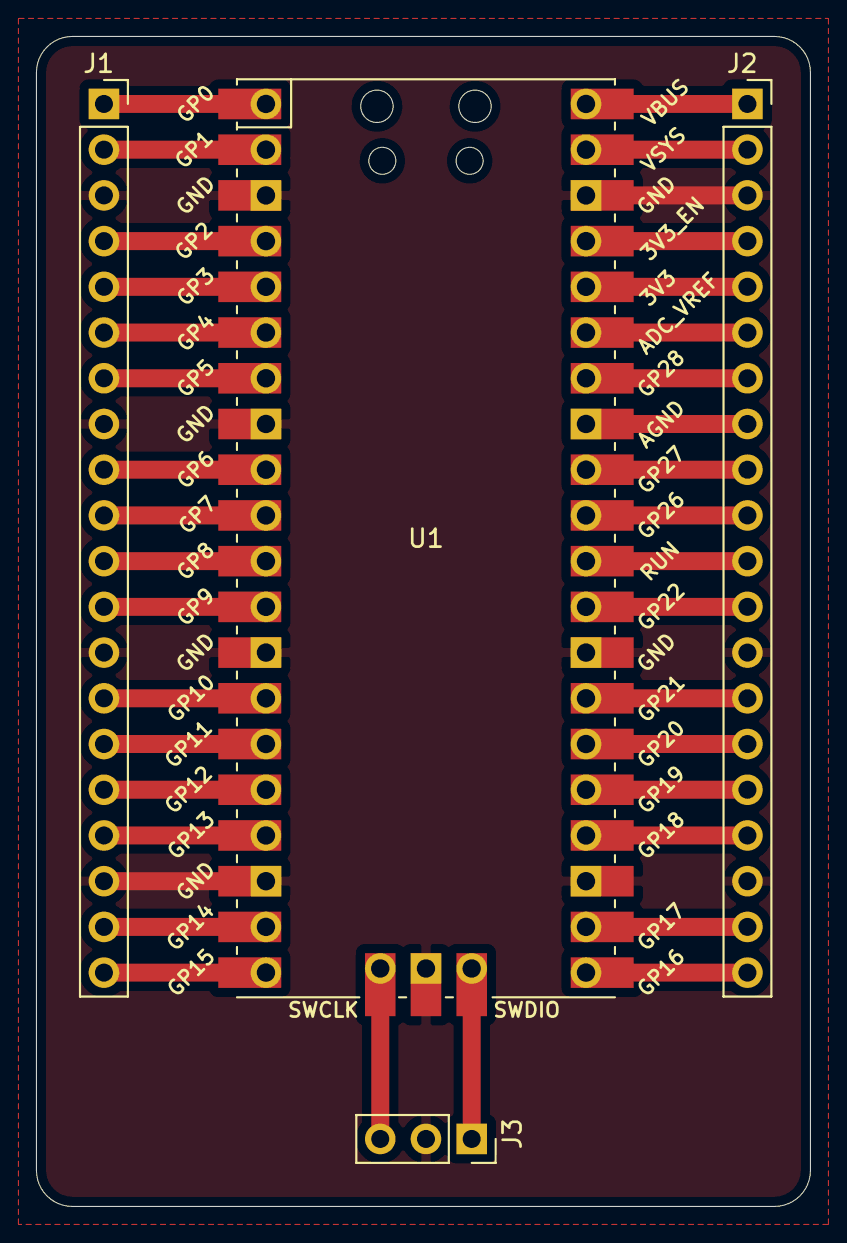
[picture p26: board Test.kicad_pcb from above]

Board: 2 copper layers, 43.0 x 65.0 mm, 4 parts (0 on the bottom side), 36 nets.

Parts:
J1, J2: Conn_01x20; PinSocket_1x20_P2.54mm_Vertical
J3: Conn_01x03; PinSocket_1x03_P2.54mm_Vertical
U1: Pico; RPi_Pico_SMD_TH

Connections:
GND: J1.3, J1.8, J1.13, J1.18, J2.3, J2.13, J2.18, J3.2, U1.3, U1.8, U1.13, U1.18, U1.23, U1.28, U1.38, U1.42
unnamed: J1.1, U1.1
unnamed: J1.2, U1.2
unnamed: J1.4, U1.4
unnamed: J1.5, U1.5
unnamed: J1.6, U1.6
unnamed: J1.7, U1.7
unnamed: J1.9, U1.9
unnamed: J1.10, U1.10
unnamed: J1.11, U1.11
unnamed: J1.12, U1.12
unnamed: J1.14, U1.14
unnamed: J1.15, U1.15
unnamed: J1.16, U1.16
unnamed: J1.17, U1.17
unnamed: J1.19, U1.19
unnamed: J1.20, U1.20
unnamed: J2.1, U1.40
unnamed: J2.2, U1.39
unnamed: J2.4, U1.37
unnamed: J2.5, U1.36
unnamed: J2.6, U1.35
unnamed: J2.7, U1.34
unnamed: J2.8, U1.33
unnamed: J2.9, U1.32
unnamed: J2.10, U1.31
unnamed: J2.11, U1.30
unnamed: J2.12, U1.29
unnamed: J2.14, U1.27
unnamed: J2.15, U1.26
unnamed: J2.16, U1.25
unnamed: J2.17, U1.24
unnamed: J2.19, U1.22
unnamed: J2.20, U1.21
unnamed: J3.1, U1.43
unnamed: J3.3, U1.41

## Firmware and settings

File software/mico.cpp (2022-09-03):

#include "bsp/board.h"
#include "hardware/gpio.h"
#include "hardware/interp.h"
#include "hardware/pio.h"
#include "hardware/structs/ioqspi.h"
#include "hardware/structs/sio.h"
#include "libs/encoder-pio/pioencoder.hpp"
#include "mico_midi.h"
#include "micoencoder.hpp"
#include "pico/binary_info.h"
#include "pico/stdlib.h"
#include "tusb.h"
#include "velocity.hpp"
#include "voice.hpp"
#include "timeralarm.hpp"
#include <stdio.h>

// Change this to true to enable parallel channel mode
#define PARALLEL_CHANNELS false

using namespace pimoroni;
using namespace mico;

auto clipmode = ClipMode::WRAP;
constexpr int channel = 1;
constexpr int numEncoders = 4;
#define LED_PIN PICO_DEFAULT_LED_PIN
bool buttonState;

// A voice is an encoder with midi sender, encoder class, velocity etc.
MicoVoice voices[numEncoders]{
  MicoVoice(4, 5, 14, channel, clipmode),
  MicoVoice(2, 3, 15, channel, clipmode),
  MicoVoice(8, 9, 16, channel, clipmode),
  MicoVoice(6, 7, 17, channel, clipmode),
};

void changeClipmodes(ClipMode newMode){
  for (size_t i = 0; i < numEncoders; i++) {
	voices[i].setClipMode(newMode);
  }
}

pico_arduino::TimerAlarmRepeating miditimer;

// UART defines
// By default the stdout UART is `uart0`, so we will use the second one
#define UART_ID uart0
#define BAUD_RATE 115200

// Device mounting callbacks
void tud_mount_cb(void) {
  printf("Mico mounted\n");
} // Invoked when device is mounted
void tud_umount_cb(void) {
  printf("Mico unmounted\n");
} // Invoked when device is unmounted
void tud_suspend_cb(bool remote_wakeup_en) {
  printf("Mico suspended\n");
} // Invoked when usb bus is suspended
void tud_resume_cb(void) {
  printf("Mico resumed\n");
} // Invoked when usb bus is resumed

// Picoboard has a button attached to the flash CS pin, which the bootrom
// checks, and jumps straight to the USB bootcode if the button is pressed
// (pulling flash CS low). We can check this pin in by jumping to some code in
// SRAM (so that the XIP interface is not required), floating the flash CS
// pin, and observing whether it is pulled low.
//
// This doesn't work if others are trying to access flash at the same time,
// e.g. XIP streamer, or the other core.
bool __no_inline_not_in_flash_func(get_bootsel_button)() {
  const uint CS_PIN_INDEX = 1;

  // Must disable interrupts, as interrupt handlers may be in flash, and we
  // are about to temporarily disable flash access!
  uint32_t flags = save_and_disable_interrupts();

  // Set chip select to Hi-Z
  hw_write_masked(&ioqspi_hw->io[CS_PIN_INDEX].ctrl,
                  GPIO_OVERRIDE_LOW << IO_QSPI_GPIO_QSPI_SS_CTRL_OEOVER_LSB,
                  IO_QSPI_GPIO_QSPI_SS_CTRL_OEOVER_BITS);

  // Note we can't call into any sleep functions in flash right now
  for (volatile int i = 0; i < 1000; ++i)
    ;

  // The HI GPIO registers in SIO can observe and control the 6 QSPI pins.
  // Note the button pulls the pin *low* when pressed.
  bool button_state = !(sio_hw->gpio_hi_in & (1u << CS_PIN_INDEX));

  // Need to restore the state of chip select, else we are going to have a
  // bad time when we return to code in flash!
  hw_write_masked(&ioqspi_hw->io[CS_PIN_INDEX].ctrl,
                  GPIO_OVERRIDE_NORMAL << IO_QSPI_GPIO_QSPI_SS_CTRL_OEOVER_LSB,
                  IO_QSPI_GPIO_QSPI_SS_CTRL_OEOVER_BITS);

  restore_interrupts(flags);

  return button_state;
}

void midi_task(void) {
  for (size_t voiceNum = 0; voiceNum < numEncoders; voiceNum++) {
    voices[voiceNum].update14();
  }
}

void button_task() {
  auto newState = get_bootsel_button();
  if (buttonState != newState) {
    buttonState = newState;

    // Toggle
    if (buttonState == 1) {
	  switch (clipmode) {
		case ClipMode::CLAMP:
		  clipmode = ClipMode::WRAP;
		  gpio_put(LED_PIN, 0);
		  break;
		case ClipMode::WRAP:
		  clipmode = ClipMode::CLAMP;
		  gpio_put(LED_PIN, 1);
		  break;
	  }

	  changeClipmodes(clipmode);
      printf("Changed clipmode to: %d\n", clipmode);
    }
  }
}

static bool loopTask(repeating_timer_t *rt){
  tud_task(); // tinyusb device task
  button_task();
  midi_task();
  return true;
}

inline void setup() {

  printf("Setting up Mico.\n");
  buttonState = get_bootsel_button();

  for (size_t voiceNum = 0; voiceNum < numEncoders; voiceNum++) {
    voices[voiceNum].init();
  }

  // Turn on LED
  gpio_init(LED_PIN);
  gpio_set_dir(LED_PIN, GPIO_OUT);
  gpio_put(LED_PIN, 0);

  printf("Starting midi timer\n");
  miditimer.start(loopTask, 1);
}
int main() {
  printf("Starting Mico main loop.\n");
  // TODO: Is this already done by Pico sdk?
  board_init();
  // Set up our UART
  uart_init(UART_ID, BAUD_RATE);
  stdio_init_all();
  tusb_init();
  setup();

  printf("Starting Mico loop.\n");

  while (true) {
    // sleep_ms(1);
  }

  return 0;
}

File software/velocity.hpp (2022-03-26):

/*
*
* TODO:
* - This whole business is probably overcomplicated somewhat. Clean it up and simplify it!
*
*/
#pragma once
#ifndef VEL
#define VEL

namespace mico{

enum Speed {
  SLOWEST=100000,
  SLOW=50000,
  MEDIUM=30000,
  FAST=20000,
  SUPERFAST=10000,
  FASTEST=5000,
};

// std::array<int, Speed::NUM_SPEEDS> deltaValues = {
//   1000,
//   500,
//   250,
//   50,
//   10,
//   5,
//   1,
// };

class Velocity {
public:
  // This is used outside of the class to figure out what level of velocity we are at.
  int speed_level{1};
  static const int num_speed_levels{7};

  void init(){
	t2 = time_us_32();
	update();
  }

  // Update clocks and return the delta value (velocity applied to 14 bit midi value range)
  uint32_t next14(){
	auto deltaval = update();
	return get_delta_value14(deltaval);
  }
private:
  uint32_t t2{1}, t1{1};
  // Generate a value suitable for increasing/decreasing a 14 bit value based on a time delta between two different times of polling that value. Expects microseconds. Use `time_us_32()`
  uint32_t update(){
	t1 = time_us_32();
	const auto time_delta = t1 - t2;
	t2 = t1;
	printf("time delta: %d\n", time_delta);
	return time_delta;
  }

  uint32_t get_delta_value14(uint32_t time_delta) {
	constexpr auto ultrafast = 5500;
	constexpr auto superfast = 10000;
	constexpr auto fast = 20000;
	constexpr auto mediumfast = 50000;
	constexpr auto medium = 75000;
	constexpr auto lowspeed = 100000;

	if (time_delta < superfast && time_delta > 0) {
	  speed_level = 7;
	  return 1000;
	} else if (time_delta > ultrafast && time_delta < superfast) {
	  speed_level = 6;
	  return 500;
	} else if (time_delta > superfast && time_delta < fast) {
	  speed_level = 5;
	  return 250;
	} else if (time_delta > fast && time_delta < mediumfast) {
	  speed_level = 4;
	  return 50;
	} else if (time_delta > mediumfast && time_delta < medium) {
	  speed_level = 3;
	  return 10;
	} else if (time_delta > medium && time_delta < lowspeed) {
	  speed_level = 2;
	  return 5;
	} else {
	  speed_level = 1;
	  return 1;
	}
  }
};

}

#endif

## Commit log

2022-02-23 harware v1 done
    [encoder_no_switch.kicad_sch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]
2022-02-23 non-working enclosure
    [mico.scad]
2022-02-24 rename Encoder to PioEncoder and make MicoEncoder class
2022-02-27 Mico-encoder class finished and all encoders now working
2022-02-27 feat: cycle through clip modes using button
2022-02-28 Refactor each encoder as a MicoVoice
2022-03-01 Move all tasks into timer
2022-03-01 fix: time_delta could potentially add max value infinitely if 0
    [velocity.hpp]
2022-03-01 Tune velocity a bit
2022-03-02 add 3d models to pcb layout
    [Rotary Encoder.step, mico.kicad_pcb]
2022-03-02 Make 3d model of all electronics (for enclosure work)
    [Pico.skp, Raspberry Pi Pico.step, Test.kicad_pcb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]
2022-03-02 add enclosure
    [mico-box.scad, mico_box.stl]
2022-03-03 finish print
    [back.stl, bottom.stl, front.stl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]
2022-03-03 tune box
    [mico.scad]
2022-03-26 Initial support for velocity trigger note on/off
2022-06-22 fix: Change midi cc channels to go from 14
    [mico.cpp]
2022-06-22 fix: make parallel mode optional using flag
    [mico.cpp]
2022-06-22 fix: Clamping mode did not clamp to 0.0-1.0
    [mico.cpp]
2022-09-03 fix: Midi timer not called often enough for MacOS
    [mico.cpp]
